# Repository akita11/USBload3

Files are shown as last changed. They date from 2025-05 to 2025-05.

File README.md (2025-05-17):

# USBload3

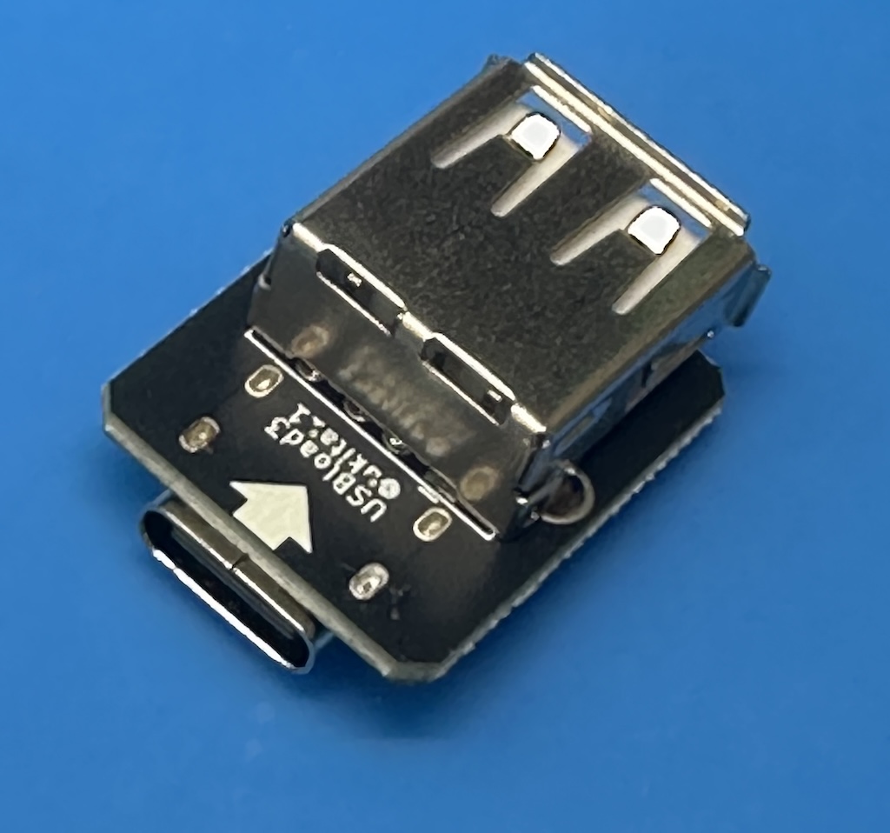
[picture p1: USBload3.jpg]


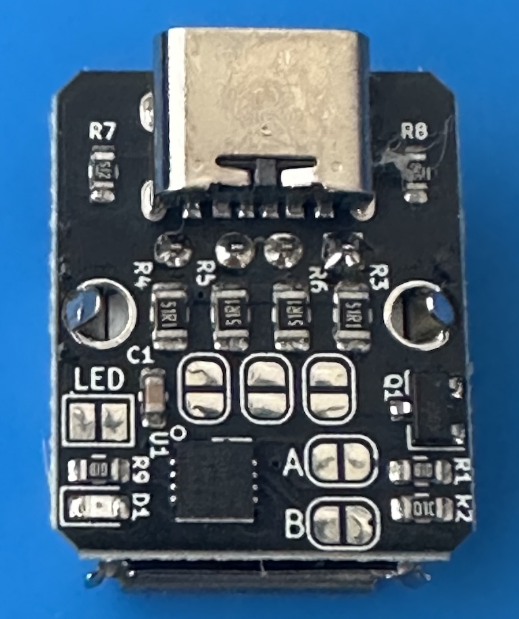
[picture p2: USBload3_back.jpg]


モバイルバッテリをマイコンボード等で給電するときに、電源が切れてしまう現象を回避するためのものです。定期的に負荷をかける（少し電流を流す）ことで、電源が切れることを回避します。流す電流量と電流を流す周期は設定できます。[USBload](https://github.com/akita11/USBload)と機能は同一で、受電側のUSBコネクタのみ異なります。

## 使い方

- 本機のUSB Aコネクタとマイコンボード等を、市販のUSBケーブルで接続する
- 本機のUSB TypeCコネクタとモバイルバッテリを、市販のUSBケーブルで接続する

モバイルバッテリを接続すると動作がはじまります。負荷がかかっている（電流が流れている）ときには本体LEDが点灯します。

## 設定の変更

[USBload](https://github.com/akita11/USBload)の資料を参照してください。なお負荷時のLEDは、LED横の「LED」と書いてあるパターン（半田ジャンパ）をカットすることでOFFにできます。

## Author

Junichi Akita (@akita11) / akita@ifdl.jp

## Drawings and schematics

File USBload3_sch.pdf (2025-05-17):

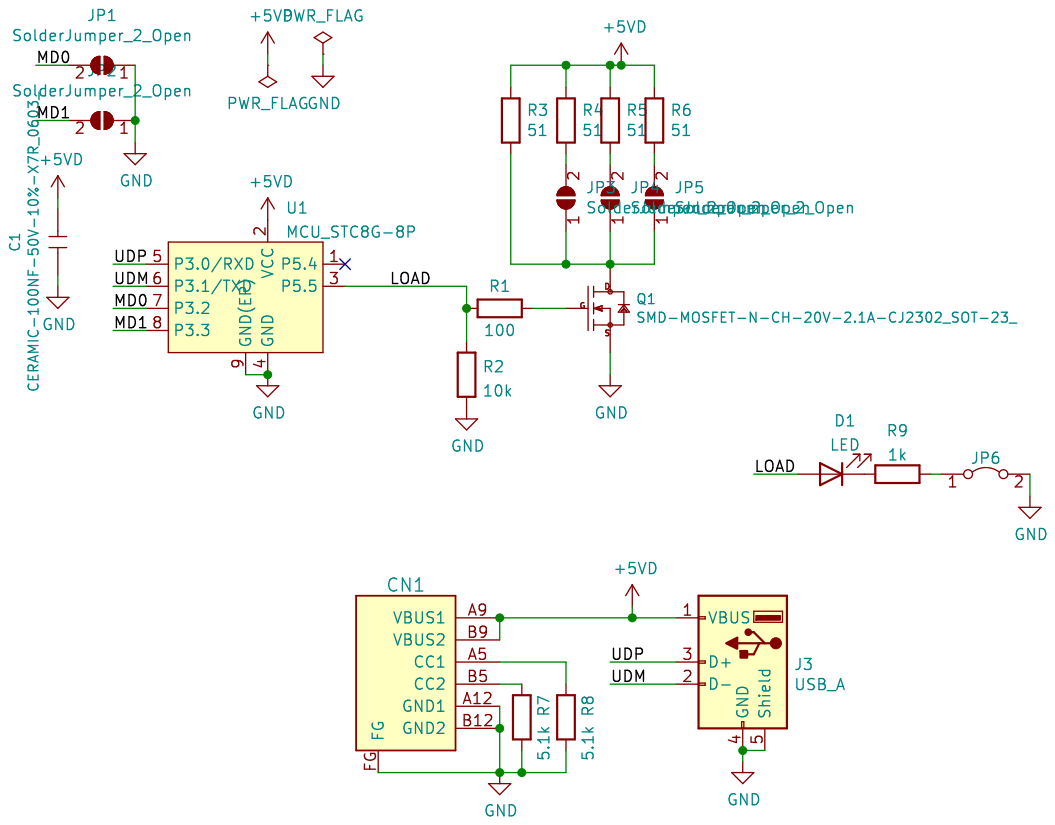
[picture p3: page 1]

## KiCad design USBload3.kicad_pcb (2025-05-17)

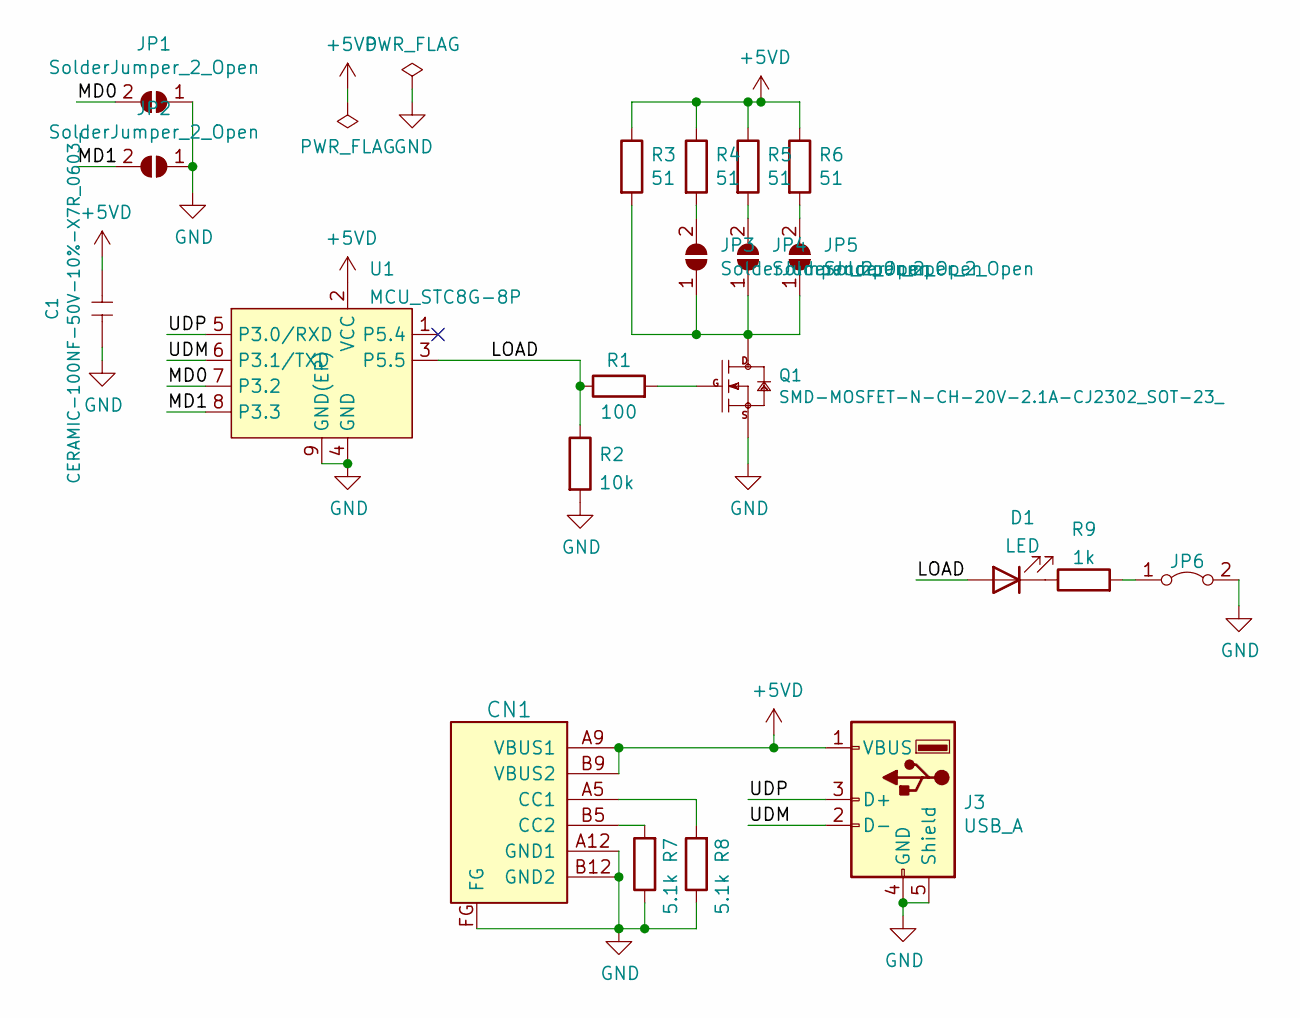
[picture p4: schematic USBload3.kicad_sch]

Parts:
C1: CERAMIC-100NF-50V-10%-X7R_0603_; C_0603_1608Metric; MPN CC0603KRX7R9BB104
CN1: CON_USB-C-6; USB-C_6P
D1: LED; LED_0603_1608Metric
J3: USB_A; USB_A_Stewart_SS-52100-001_Horizontal
JP1, JP2, JP3, JP4, JP5: SolderJumper_2_Open; SolderJumper-2_P1.3mm_Open_RoundedPad1.0x1.5mm
JP6: Jumper_2_Bridged; SolderJumper-2_P1.3mm_Bridged_Pad1.0x1.5mm
Q1: SMD-MOSFET-N-CH-20V-2.1A-CJ2302_SOT-23_; SOT-23; MPN CJ2302
R1: 100; R_0603_1608Metric
R2: 10k; R_0603_1608Metric
R3, R4, R5, R6: 51; R_0805_2012Metric
R7, R8: 5.1k; R_0603_1608Metric
R9: 1k; R_0603_1608Metric
U1: MCU_STC8G-8P; DFN-8-1EP_3x3mm_P0.5mm_EP1.66x2.38mm

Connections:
+5VD: C1.2, CN1.A9 (VBUS1), CN1.B9 (VBUS2), J3.1 (VBUS), R3.1, R4.1, R5.1, R6.1, U1.2 (VCC)
/LOAD: D1.2 (A), R1.1, R2.1, U1.3 (P5.5)
/MD0: JP1.2 (B), U1.7 (P3.2)
/MD1: JP2.2 (B), U1.8 (P3.3)
/UDM: J3.2 (D-), U1.6 (P3.1/TXD)
/UDP: J3.3 (D+), U1.5 (P3.0/RXD)
GND: C1.1, CN1.A12 (GND1), CN1.B12 (GND2), CN1.FG, J3.4 (GND), J3.5 (Shield), JP1.1 (A), JP2.1 (A), JP6.2 (B), Q1.2 (S), R2.2, R7.1, R8.1, U1.4 (GND), U1.9 (GND(EP))
unnamed: CN1.A5 (CC1), R8.2
unnamed: CN1.B5 (CC2), R7.2
unnamed: D1.1 (K), R9.1
unnamed: JP3.1 (A), JP4.1 (A), JP5.1 (A), Q1.3 (D), R3.2
unnamed: JP3.2 (B), R4.2
unnamed: JP4.2 (B), R5.2
unnamed: JP5.2 (B), R6.2
unnamed: JP6.1 (A), R9.2
unnamed: Q1.1 (G), R1.2

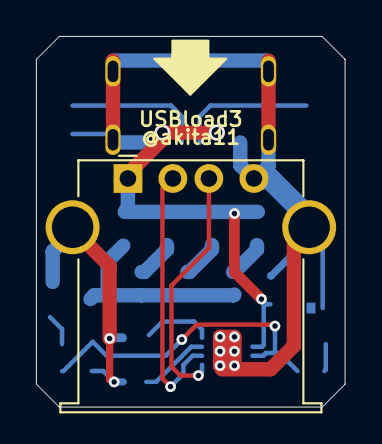
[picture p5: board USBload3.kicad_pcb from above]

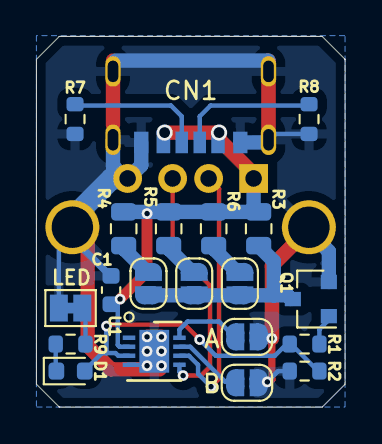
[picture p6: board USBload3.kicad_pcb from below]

Board: 2 copper layers, 17.1 x 20.6 mm, 21 parts (20 on the bottom side), 16 nets.
